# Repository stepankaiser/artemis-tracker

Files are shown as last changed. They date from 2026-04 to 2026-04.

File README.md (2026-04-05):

# Artemis II Live Tracker

A real-time LED strip + phone dashboard that tracks NASA's Artemis II spacecraft on its journey to the Moon and back, using live telemetry from JPL Horizons.

Built during the live mission (April 1-11, 2026) as a family weekend project.

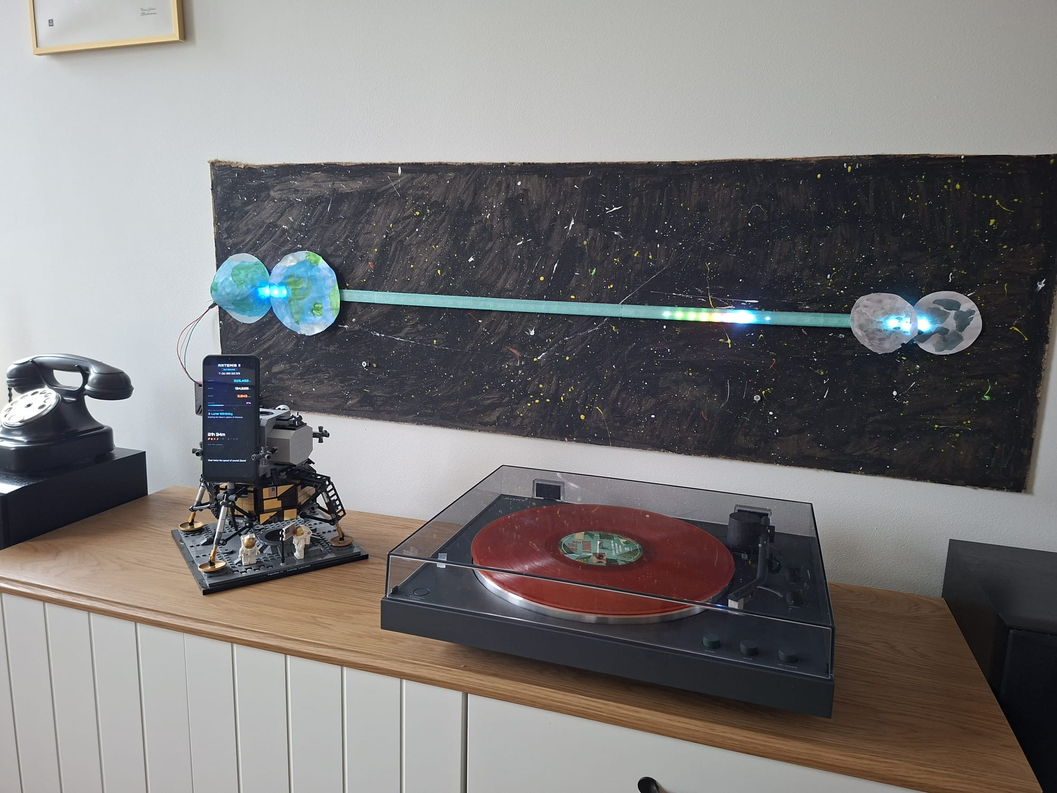
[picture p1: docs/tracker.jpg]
Artemis II Tracker


## What It Does

- **60-LED strip** shows spacecraft position between Earth and Moon in real-time
- **Android phone dashboard** displays live stats, milestone countdowns, and AI-generated fun facts
- **Startup animation** — rocket flies from Earth to current position on each power-on
- **Phase-aware effects** — different visuals for outbound, lunar flyby, return, reentry, and splashdown
- **Fully autonomous** — plug in power, everything starts automatically

## Hardware

| Component | Details |
|---|---|
| Raspberry Pi 5 | Running the tracker software |
| WS2812 LED Strip | 60 LEDs, 1m, 5V, addressable RGB |
| Android Phone | Samsung Galaxy A13 (any Android with USB debugging works) |
| 5V Power Supply | 4A+ for Pi + LED strip |
| 3D Printed Channel | LED diffuser with translucent PETG cap |

### Wiring

```
Pi GPIO 10 (SPI MOSI, Pin 19) → LED Strip DIN
Pi Pin 2 (5V)                  → LED Strip VCC
Pi Pin 6 (GND)                 → LED Strip GND
Phone                          → Pi USB port (ADB)
```

## LED Effects

```
[Earth 🔵🔵🔵] · · · · ★🚀🔴🟠🟡· · · · · · [🌕🌕🌕 Moon]
  bright blue                                   bright white
  3 LEDs          rocket + exhaust plume         3 LEDs
```

| Phase | Effect |
|---|---|
| **Outbound** | Blue-white capsule + red/orange/yellow exhaust plume |
| **Flyby** | Blue shimmer near Moon, golden pulse when distance record broken |
| **Return** | Comet tail flips direction |
| **Reentry** | Fireball mode — red-hot rapid flicker, heat glow on Earth end |
| **Splashdown** | Rainbow celebration → ocean breathing → trophy mode |

## Phone Dashboard

Space-themed fullscreen dashboard via FastAPI + WebSocket:

- Live distance from Earth/Moon, speed, MET
- Mission progress bar
- Next milestone countdown with emoji timeline
- AI-powered fun facts (Gemini API, refreshed hourly)

## Data Source

**JPL Horizons API** — NASA's authoritative ephemeris system. The spacecraft is tracked as ID `-1024`. No API key needed. Polled every 5 minutes with exponential backoff on failure and position interpolation between polls.

## Quick Start

### On the Raspberry Pi 5

```bash
# Clone
git clone https://github.com/stepankaiser/artemis-tracker.git
cd artemis-tracker

# Setup (installs Python venv, LED/OLED libraries, enables SPI/I2C)
bash setup_pi.sh

# Run in demo mode (simulates full mission in 2 minutes)
source .venv/bin/activate
python -m artemis --demo

# Run live (real Artemis II data)
python -m artemis
```

### Phone Display

Connect an Android phone with USB debugging enabled:

```bash
bash setup_phone.sh
```

### Auto-Start on Boot

```bash
sudo cp artemis-tracker.service /etc/systemd/system/
sudo cp artemis-phone.service /etc/systemd/system/
sudo systemctl daemon-reload
sudo systemctl enable artemis-tracker artemis-phone
```

## Project Structure

```
artemis/
├── tracker.py        # Main loop — 30fps LED rendering, 1Hz display updates
├── horizons.py       # JPL Horizons API client with interpolation & backoff
├── leds.py           # LED effects engine — all mission phases
├── display.py        # SSD1306 OLED driver (optional, if you have one)
├── web.py            # FastAPI + WebSocket server for phone dashboard
├── dashboard.html    # Space-themed responsive dashboard
├── facts.py          # Gemini-powered fun fact generator
└── config.py         # Mission timeline, milestones, crew data
```

## Raspberry Pi 5 Notes

The Pi 5 uses the RP1 I/O chip which changes how SPI and I2C work:

- **SPI**: Device is `/dev/spidev10.0` (not `spidev0.0`). Pins must be set to alt function with `pinctrl set 10 a0` before each start.
- **I2C**: Hardware I2C may be on bus 1 or 3 depending on overlays. The code auto-detects.
- **LED Library**: Uses `adafruit-circuitpython-neopixel-spi` (the classic `rpi_ws281x` doesn't work on Pi 5).

## Mission Timeline

| Event | Date (UTC) | Status |
|---|---|---|
| Launch | Apr 1, 22:35 | Completed |
| TLI Burn | Apr 2, 23:49 | Completed |
| Lunar SOI Entry | Apr 6, 04:43 | Upcoming |
| Lunar Flyby (6,513 km) | Apr 6, 23:06 | Upcoming |
| Max Distance Record | Apr 6, 23:09 | Upcoming |
| Splashdown | Apr 11, 00:17 | Upcoming |

## Built With

- Python 3.13, FastAPI, uvicorn
- adafruit-circuitpython-neopixel-spi
- JPL Horizons API
- Google Gemini API (fun facts)
- Bambu Lab A1 Mini (3D printed LED channel)

## License

MIT

---

Built with a lot of excitement during the Artemis II mission by Stepan Kaiser and family, with help from [Claude Code](https://claude.ai/claude-code).

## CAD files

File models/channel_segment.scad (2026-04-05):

// ============================================
// Artemis II LED Tracker - Channel Segment
// Print 6x in silk specter filament
// Bambu Lab A1 Mini (180x180x180mm)
// ============================================
// Settings: 0.2mm layer height, 3 walls, 15% infill
// Orientation: print flat (base down)
// ============================================

/* [Strip Properties] */
strip_width = 12;          // LED strip width (mm)
strip_clearance = 0.5;     // Clearance each side of strip (mm)

/* [Channel Dimensions] */
wall = 2;                  // Side wall thickness (mm)
base = 2;                  // Bottom thickness (mm)
total_height = 10;         // Total wall height (mm)
lip_inset = 1.5;           // Inward lip width - holds diffuser (mm)
lip_h = 1.2;               // Lip thickness (mm)

/* [Segment] */
leds_per_seg = 10;         // LEDs per segment (10 x 6 = 60 total)
led_pitch = 16.667;        // LED spacing (mm) = 1000/60

/* [Joint - tab/slot connection] */
tab_len = 8;               // Tab length (mm)
tab_w = 8;                 // Tab width (mm)
tab_h = 4;                 // Tab height (mm)
tol = 0.2;                 // Joint tolerance (mm)

/* [Mounting] */
screw_d = 4;               // Screw hole diameter (mm)

/* [Computed - do not change] */
seg_len = leds_per_seg * led_pitch;  // ~166.67mm
inner_w = strip_width + strip_clearance * 2;  // 13mm
outer_w = inner_w + wall * 2;  // 17mm
$fn = 30;

module channel_segment() {
    difference() {
        union() {
            // Solid block, then carve out the channel
            cube([outer_w, seg_len, total_height]);

            // Male tab (+Y end)
            translate([(outer_w - tab_w) / 2, seg_len - 0.01, base])
                cube([tab_w, tab_len + 0.01, tab_h]);
        }

        // Carve main channel (full inner height, but leave lips)
        // Lower portion: full inner width (below lips)
        translate([wall, -0.01, base])
            cube([inner_w, seg_len + 0.02, total_height - base - lip_h + 0.01]);

        // Upper portion: only between lips (narrower)
        translate([wall + lip_inset, -0.01, total_height - lip_h - 0.01])
            cube([inner_w - lip_inset * 2, seg_len + 0.02, lip_h + 0.02]);

        // Female slot (-Y end)
        translate([(outer_w - tab_w) / 2 - tol, -0.01, base - tol])
            cube([tab_w + tol * 2, tab_len + tol + 0.01, tab_h + tol * 2]);

        // Mounting screw holes
        for (y = [seg_len * 0.3, seg_len * 0.7])
            translate([outer_w / 2, y, -0.01])
                cylinder(d = screw_d, h = base + 0.02);
    }
}

channel_segment();

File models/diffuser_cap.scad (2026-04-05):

// ============================================
// Artemis II LED Tracker - Diffuser Cap
// Print 6x in WHITE PLA
// Bambu Lab A1 Mini (180x180x180mm)
// ============================================
// Settings: 0.2mm layer height, 2 walls, 0% infill
// This gives ~0.8mm wall thickness = great diffusion
// TIP: Enable "fuzzy skin" in Bambu Studio for
//      an even better frosted-glass look
// ============================================

/* [Must match channel_segment.scad values] */
strip_width = 12;
strip_clearance = 0.5;
wall = 2;
total_height = 10;
lip_inset = 1.5;
lip_h = 1.2;
leds_per_seg = 10;
led_pitch = 16.667;

/* [Diffuser Properties] */
diff_thick = 1.0;          // Top surface thickness (mm) - thin = more glow
side_h = 2.0;              // Side tab height (mm) - sits on lips
fit_gap = 0.3;             // Clearance for easy slide-in fit (mm)
end_gap = 0.5;             // Shorten slightly so it slides in easily (mm)

/* [Computed] */
seg_len = leds_per_seg * led_pitch;
inner_w = strip_width + strip_clearance * 2;
cap_w = inner_w - fit_gap * 2;          // Fits between channel walls
cap_len = seg_len - end_gap * 2;        // Slightly shorter than channel
free_span = inner_w - lip_inset * 2;    // Open gap between lips
tab_w = (cap_w - free_span) / 2 + 0.3; // Tab overlap on each lip

module diffuser_cap() {
    // Flat diffuser top
    translate([0, 0, side_h])
        cube([cap_w, cap_len, diff_thick]);

    // Left side tab (rests on lip)
    cube([tab_w, cap_len, side_h + diff_thick]);

    // Right side tab (rests on lip)
    translate([cap_w - tab_w, 0, 0])
        cube([tab_w, cap_len, side_h + diff_thick]);
}

diffuser_cap();

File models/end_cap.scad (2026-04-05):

// ============================================
// Artemis II LED Tracker - End Cap
// Print 2x (one for each end of the strip)
// Print in silk specter to match channels
// ============================================
// Settings: 0.2mm layer height, 3 walls, 15% infill
// ============================================

/* [Must match channel_segment.scad values] */
strip_width = 12;
strip_clearance = 0.5;
wall = 2;
base = 2;
total_height = 10;

/* [End Cap] */
cap_depth = 3;             // How deep the cap plugs into channel (mm)
cap_thick = 2;             // End wall thickness (mm)
tol = 0.25;                // Fit tolerance (mm)
wire_hole_d = 5;           // Hole for wire pass-through (mm), set to 0 for solid

/* [Computed] */
inner_w = strip_width + strip_clearance * 2;
outer_w = inner_w + wall * 2;
inner_h = total_height - base;

module end_cap() {
    difference() {
        union() {
            // Outer face (flush with channel end)
            cube([outer_w, cap_thick, total_height]);

            // Inner plug (slides into channel)
            translate([wall + tol, -cap_depth, base + tol])
                cube([inner_w - tol * 2, cap_depth + 0.01, inner_h - tol * 2]);
        }

        // Wire pass-through hole (for data + power cables)
        if (wire_hole_d > 0)
            translate([outer_w / 2, -cap_depth - 0.01, base + inner_h / 2])
                rotate([-90, 0, 0])
                    cylinder(d = wire_hole_d, h = cap_depth + cap_thick + 0.02, $fn = 30);
    }
}

end_cap();

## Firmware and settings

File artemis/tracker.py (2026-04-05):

"""Artemis II LED Tracker — main entry point.

Usage:
  python -m artemis              # auto-detect hardware
  python -m artemis --simulate   # no hardware, log only
  python -m artemis --demo       # fake moving spacecraft for testing
"""

import argparse
import asyncio
import logging
import math
import signal
import sys
import time
from datetime import datetime, timezone

from .config import HORIZONS_POLL_INTERVAL_S, LAUNCH_TIME, MILESTONES, SPLASHDOWN_TIME
from .display import OLEDDisplay
from .facts import FactGenerator
from .horizons import HorizonsTracker
from .leds import LEDController

# Web server is optional — phone display
try:
    from .web import run_web_server, update_web_state
    HAS_WEB = True
except ImportError:
    HAS_WEB = False
    def update_web_state(*a): pass

logging.basicConfig(
    level=logging.INFO,
    format="%(asctime)s [%(name)s] %(message)s",
    datefmt="%H:%M:%S",
)
logger = logging.getLogger("artemis")

FPS = 30
FRAME_INTERVAL = 1.0 / FPS
OLED_INTERVAL = 1.0


def get_phase(now, state=None):
    """Determine mission phase using both timeline and live data."""
    if now < LAUNCH_TIME:
        return "prelaunch"

    tli = MILESTONES[3].time
    soi_in = MILESTONES[4].time
    soi_out = MILESTONES[7].time
    entry = MILESTONES[9].time
    splash = MILESTONES[10].time

    # If we have live data, use it for better phase detection
    if state:
        ratio = state.get("position_ratio", 0)
        dist_moon = state.get("dist_moon_km", 999999)
        dist_earth = state.get("dist_earth_km", 0)

        # Post-splashdown: clock past splashdown AND very close to Earth or data stale
        if now > splash and (dist_earth < 500 or state.get("data_stale", False)):
            return "splashdown"

        # Reentry: within 13 min of splashdown and close to Earth
        if now > entry and dist_earth < 50_000:
            return "reentry"

        # Flyby: near the Moon
        if dist_moon < 50_000 and ratio > 0.85:
            return "flyby"

        # Return: ratio is decreasing (heading home) and past SOI exit
        if state.get("is_return", False) and now > soi_in:
            return "return"

    # Fallback to timeline
    if now < tli:
        return "earth_orbit"
    if now < soi_in:
        return "outbound"
    if now < soi_out:
        return "flyby"
    if now < entry:
        return "return"
    if now < splash:
        return "reentry"
    return "splashdown"


class DemoTracker:
    """Fake tracker simulating the full mission in 2 minutes."""

    def __init__(self):
        self.spacecraft = None
        self.moon = None
        self._start = time.time()
        self.last_update_time = time.time()
        self.staleness_seconds = 0
        self._last_velocity_ratio = 0

    async def start(self):
        logger.info("Demo mode: full mission in 2 minutes")

    async def stop(self):
        pass

    async def update(self):
        pass

    def interpolated_ratio(self):
        return self.get_demo_state()["position_ratio"]

    def get_demo_state(self):
        elapsed = time.time() - self._start
        cycle = (elapsed % 120) / 120  # 2-minute full mission

        # Mission profile: outbound (0-0.45), flyby (0.45-0.55), return (0.55-1.0)
        if cycle < 0.45:
            ratio = (cycle / 0.45) * 1.05  # go slightly past Moon
            phase = "flyby" if ratio > 0.9 else "outbound"
        elif cycle < 0.55:
            # At/past Moon, coming back
            t = (cycle - 0.45) / 0.10
            ratio = 1.05 - t * 0.15
            phase = "flyby"
        elif cycle < 0.95:
            t = (cycle - 0.55) / 0.40
            ratio = 0.90 - t * 0.88
            phase = "return" if ratio > 0.02 else "reentry"
        else:
            ratio = 0.0
            phase = "splashdown"

        dist_earth = ratio * 400_000
        dist_moon = abs(1.0 - ratio) * 400_000
        speed = abs(math.sin(cycle * math.pi)) * 35_000 + 2_000

        return {
            "position_ratio": max(0, ratio),
            "speed_kmh": speed,
            "dist_earth_km": dist_earth,
            "dist_moon_km": dist_moon,
            "phase": phase,
            "is_return": cycle > 0.50,
            "data_stale": False,
        }

    async def poll_loop(self):
        while True:
            await asyncio.sleep(1)


async def run(args):
    simulate = args.simulate or sys.platform == "darwin"
    demo_mode = args.demo

    leds = LEDController(simulate=simulate)
    oled = OLEDDisplay(simulate=simulate)
    facts = FactGenerator()
    tracker = DemoTracker() if demo_mode else HorizonsTracker(HORIZONS_POLL_INTERVAL_S)

    shutdown = asyncio.Event()
    signal.signal(signal.SIGTERM, lambda *_: shutdown.set())
    signal.signal(signal.SIGINT, lambda *_: shutdown.set())
    signal.signal(signal.SIGUSR1, lambda *_: leds.trigger_milestone_flash())

    await leds.start()
    await oled.start()
    await facts.start()
    await tracker.start()

    # Startup animation: rocket flies to current position
    if tracker.spacecraft:
        leds.startup_animation(tracker.spacecraft.position_ratio)

    # Start web server for phone display (optional)
    web_task = None
    if HAS_WEB:
        try:
            web_task = asyncio.create_task(run_web_server())
            logger.info("Web dashboard on http://0.0.0.0:8080")
        except Exception as e:
            logger.warning(f"Web server failed: {e}")

    logger.info("=== Artemis II Tracker running ===")
    logger.info(f"Mode: {'DEMO' if demo_mode else 'SIMULATE' if simulate else 'LIVE'}")

    announced = {ms.name for ms in MILESTONES if ms.time <= datetime.now(timezone.utc)}
    poll_task = asyncio.create_task(tracker.poll_loop())

    # Track direction (outbound vs return) with a rolling window
    ratio_history = []
    last_oled = 0.0

    try:
        while not shutdown.is_set():
            frame_start = time.time()
            now = datetime.now(timezone.utc)

            if demo_mode:
                state = tracker.get_demo_state()
            elif tracker.spacecraft:
                sc = tracker.spacecraft
                # Use interpolated ratio for smoother LED movement between polls
                interp_ratio = tracker.interpolated_ratio()

                # Determine direction from ratio history
                ratio_history.append(sc.position_ratio)
                if len(ratio_history) > 5:
                    ratio_history.pop(0)
                is_return = (len(ratio_history) >= 3 and
                             ratio_history[-1] < ratio_history[0] - 0.001)

                state = {
                    "position_ratio": interp_ratio,
                    "speed_kmh": sc.speed_kmh,
                    "dist_earth_km": sc.distance_from_earth_km,
                    "dist_moon_km": sc.distance_from_moon_km,
                    "phase": "outbound",  # placeholder, computed below
                    "is_return": is_return,
                    "data_stale": tracker.staleness_seconds > 1800,
                }
                state["phase"] = get_phase(now, state)
            else:
                state = {
                    "position_ratio": 0.0, "speed_kmh": 0.0,
                    "dist_earth_km": 0.0, "dist_moon_km": 400_000.0,
                    "phase": get_phase(now), "is_return": False,
                    "data_stale": True,
                }

            # Milestone announcements
            for ms in MILESTONES:
                if ms.name not in announced and ms.time <= now:
                    announced.add(ms.name)
                    logger.info(f"MILESTONE: {ms.emoji} {ms.name} — {ms.description}")
                    leds.trigger_milestone_flash()

            # Update LEDs
            leds.position_ratio = state["position_ratio"]
            leds.speed_kmh = state["speed_kmh"]
            leds.dist_earth_km = state["dist_earth_km"]
            leds.dist_moon_km = state["dist_moon_km"]
            leds.phase = state["phase"]
            leds.is_return = state.get("is_return", False)
            leds.render()

            # Update OLED + facts (1 Hz)
            if frame_start - last_oled >= OLED_INTERVAL:
                met_hours = (now - LAUNCH_TIME).total_seconds() / 3600
                await facts.maybe_refresh(
                    state["dist_earth_km"], state["dist_moon_km"],
                    state["speed_kmh"], state["phase"], met_hours)
                oled.dist_earth = state["dist_earth_km"]
                oled.dist_moon = state["dist_moon_km"]
                oled.speed = state["speed_kmh"]
                oled.phase = state["phase"]
                oled.data_stale_seconds = tracker.staleness_seconds if not demo_mode else 0
                oled.fact_lines = facts.get_display_lines()
                oled.render()
                # Push to phone dashboard
                update_web_state(state, facts.current_fact)
                last_oled = frame_start

            elapsed = time.time() - frame_start
            await asyncio.sleep(max(0, FRAME_INTERVAL - elapsed))

    finally:
        poll_task.cancel()
        if web_task:
            web_task.cancel()
        await leds.stop()
        await oled.stop()
        logger.info("=== Tracker stopped ===")


def main():
    parser = argparse.ArgumentParser(description="Artemis II LED Tracker")
    parser.add_argument("--simulate", action="store_true")
    parser.add_argument("--demo", action="store_true")
    asyncio.run(run(parser.parse_args()))


if __name__ == "__main__":
    main()

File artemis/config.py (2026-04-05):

"""Mission configuration and timeline for Artemis II."""

from dataclasses import dataclass
from datetime import datetime, timezone

# === Hardware ===
NUM_LEDS = 60
LED_BRIGHTNESS = 0.4
SPI_SPEED_HZ = 6_400_000

# OLED (SSD1306 128x64 I2C)
OLED_WIDTH = 128
OLED_HEIGHT = 64

# === Mission Timeline (UTC) ===
LAUNCH_TIME = datetime(2026, 4, 1, 22, 35, 12, tzinfo=timezone.utc)
SPLASHDOWN_TIME = datetime(2026, 4, 11, 0, 17, 0, tzinfo=timezone.utc)

EARTH_MOON_DISTANCE_KM = 384_400  # average

# JPL Horizons IDs
HORIZONS_ARTEMIS_ID = "-1024"
HORIZONS_MOON_ID = "301"

# === API Polling ===
HORIZONS_POLL_INTERVAL_S = 300  # every 5 minutes
WEB_UPDATE_INTERVAL_S = 1       # websocket push rate

# === LED Zones ===
EARTH_LEDS = (0, 2)    # LEDs 0-2
MOON_LEDS = (57, 59)   # LEDs 57-59
SPACE_LEDS = (3, 56)   # LEDs 3-56


@dataclass
class MissionMilestone:
    name: str
    time: datetime
    description: str
    emoji: str


MILESTONES = [
    MissionMilestone(
        "Launch", LAUNCH_TIME,
        "Liftoff from LC-39B, Kennedy Space Center", "🚀"
    ),
    MissionMilestone(
        "Perigee Raise", datetime(2026, 4, 1, 23, 25, tzinfo=timezone.utc),
        "First engine burn to raise orbit", "🔥"
    ),
    MissionMilestone(
        "ICPS Separation", datetime(2026, 4, 2, 1, 59, tzinfo=timezone.utc),
        "Orion separates from upper stage", "✂️"
    ),
    MissionMilestone(
        "TLI Burn", datetime(2026, 4, 2, 23, 49, tzinfo=timezone.utc),
        "Trans-Lunar Injection — on the way to the Moon!", "🌙"
    ),
    MissionMilestone(
        "Lunar SOI Entry", datetime(2026, 4, 6, 4, 43, tzinfo=timezone.utc),
        "Entering the Moon's sphere of influence", "🌑"
    ),
    MissionMilestone(
        "Lunar Flyby", datetime(2026, 4, 6, 23, 6, tzinfo=timezone.utc),
        "Closest approach — 6,513 km from the far side!", "🎯"
    ),
    MissionMilestone(
        "Max Distance", datetime(2026, 4, 6, 23, 9, tzinfo=timezone.utc),
        "Farthest humans from Earth — 406,841 km!", "🏆"
    ),
    MissionMilestone(
        "Lunar SOI Exit", datetime(2026, 4, 7, 17, 27, tzinfo=timezone.utc),
        "Leaving the Moon's gravity, heading home", "🏠"
    ),
    MissionMilestone(
        "Manual Piloting", datetime(2026, 4, 9, 2, 55, tzinfo=timezone.utc),
        "Crew hand-flies Orion — first time since Apollo!", "🎮"
    ),
    MissionMilestone(
        "Entry Interface", datetime(2026, 4, 11, 0, 4, tzinfo=timezone.utc),
        "Hitting atmosphere at 40,000 km/h", "☄️"
    ),
    MissionMilestone(
        "Splashdown", SPLASHDOWN_TIME,
        "Safe landing in the Pacific Ocean!", "🌊"
    ),
]

CREW = [
    {"name": "Reid Wiseman", "role": "Commander", "agency": "NASA"},
    {"name": "Victor Glover", "role": "Pilot", "agency": "NASA"},
    {"name": "Christina Koch", "role": "Mission Specialist", "agency": "NASA"},
    {"name": "Jeremy Hansen", "role": "Mission Specialist", "agency": "CSA"},
]

# Fun distance comparisons (distance_km, description)
DISTANCE_COMPARISONS = [
    (1, "about as far as a 10-minute walk"),
    (12, "about as high as a commercial airplane flies"),
    (400, "as high as the International Space Station"),
    (1_000, "farther than the ISS — truly deep space now"),
    (12_742, "one Earth diameter away"),
    (35_786, "past the geostationary satellite belt"),
    (50_000, "farther than any GPS satellite"),
    (100_000, "a quarter of the way to the Moon"),
    (200_000, "halfway to the Moon"),
    (300_000, "three quarters of the way to the Moon"),
    (384_400, "at the Moon's distance!"),
    (400_171, "past Apollo 13's record — farthest humans ever!"),
]

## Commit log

2026-04-05 Artemis II Live Tracker — LED strip + phone dashboard
    Real-time spacecraft position tracker built during the live Artemis II
    mission (April 1-11, 2026). Uses JPL Horizons API for telemetry,
    60-LED WS2812 strip on Raspberry Pi 5 for position visualization,
    and an Android phone as a live dashboard via FastAPI + WebSocket.
    Features:
    - Phase-aware LED effects (outbound, flyby, return, reentry, splashdown)
    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
    [channel_segment.scad, diffuser_cap.scad, end_cap.scad]
2026-04-05 Add project photo — finished tracker on the wall
    Kids' painted Earth and Moon glowing over the LED strip,
    hand-painted starfield backdrop, phone dashboard showing
    live telemetry, next to LEGO Lunar Lander.
